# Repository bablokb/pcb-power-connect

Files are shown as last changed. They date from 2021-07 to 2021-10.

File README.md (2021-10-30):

pcb-power-connect
=================

In this repository you will find a small pcb useful if you
want to feed power to your Pi using GPIO pins 2 and 4 (e.g.
because the pi is within a housing and there is no space for
a connection to the usb-power plug of the pi).

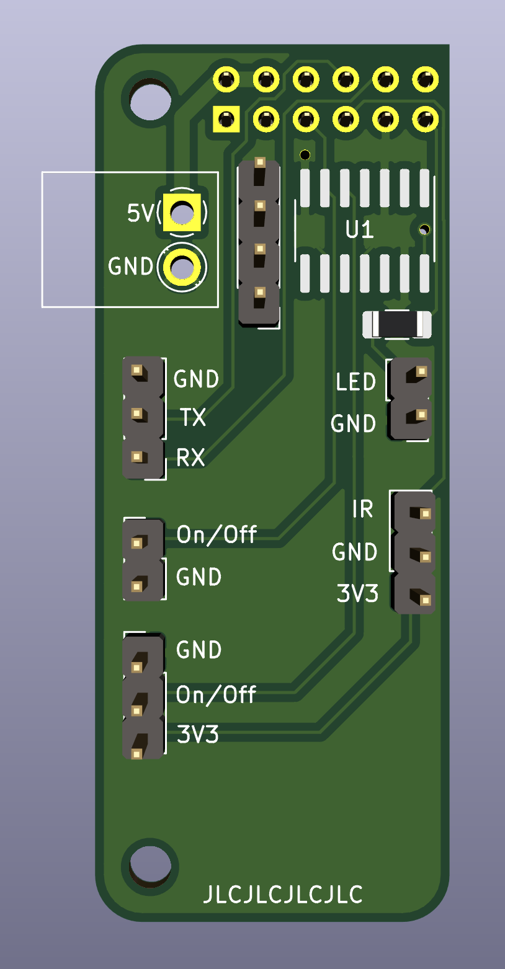
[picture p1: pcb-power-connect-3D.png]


The pcb supports some additional features

  - connect an external high->low signal (e.g. button)
    to GPIO3 (acts as on/off-switch, see below)
  - connect an external low->high signal to GPIO3 via an
    inverter (74HC05)
  - connect a LED
  - connect an IR (or something else)
  - connect an UART

 Pinout
 ------
 
  -  1: 3V3
  -  2: 5V
  -  3: GPIO2: nc
  -  4: 5V
  -  5: GPIO3: on/off
  -  6: GND
  -  7: GPIO4: IR
  -  8: GPIO14: TX
  -  9: GND
  - 10: GPIO15: RX
  - 11: GPIO17: LED
  - 12: GPIO18: nc

Configuration
-------------

Use the following configuration in `/boot/config.txt`:

    # configure GPIO3 as shutdown-button
    dtoverlay=gpio-shutdown
    
    # configure GPIO4 for IR
    dtoverlay=gpio-ir,gpio_pin=4

    # use external heartbeat-LED
    dtparam=act_led_trigger=heartbeat
    dtoverlay=act-led,gpio=17

License
-------

Shield: [![CC BY-SA 4.0][cc-by-sa-shield]][cc-by-sa]

This work is licensed under a
[Creative Commons Attribution-ShareAlike 4.0 International
License][cc-by-sa].

[][cc-by-sa]

[cc-by-sa]: http://creativecommons.org/licenses/by-sa/4.0/
[cc-by-sa-image]: https://licensebuttons.net/l/by-sa/4.0/88x31.png
[cc-by-sa-shield]:
https://img.shields.io/badge/License-CC%20BY--SA%204.0-lightgrey.svg

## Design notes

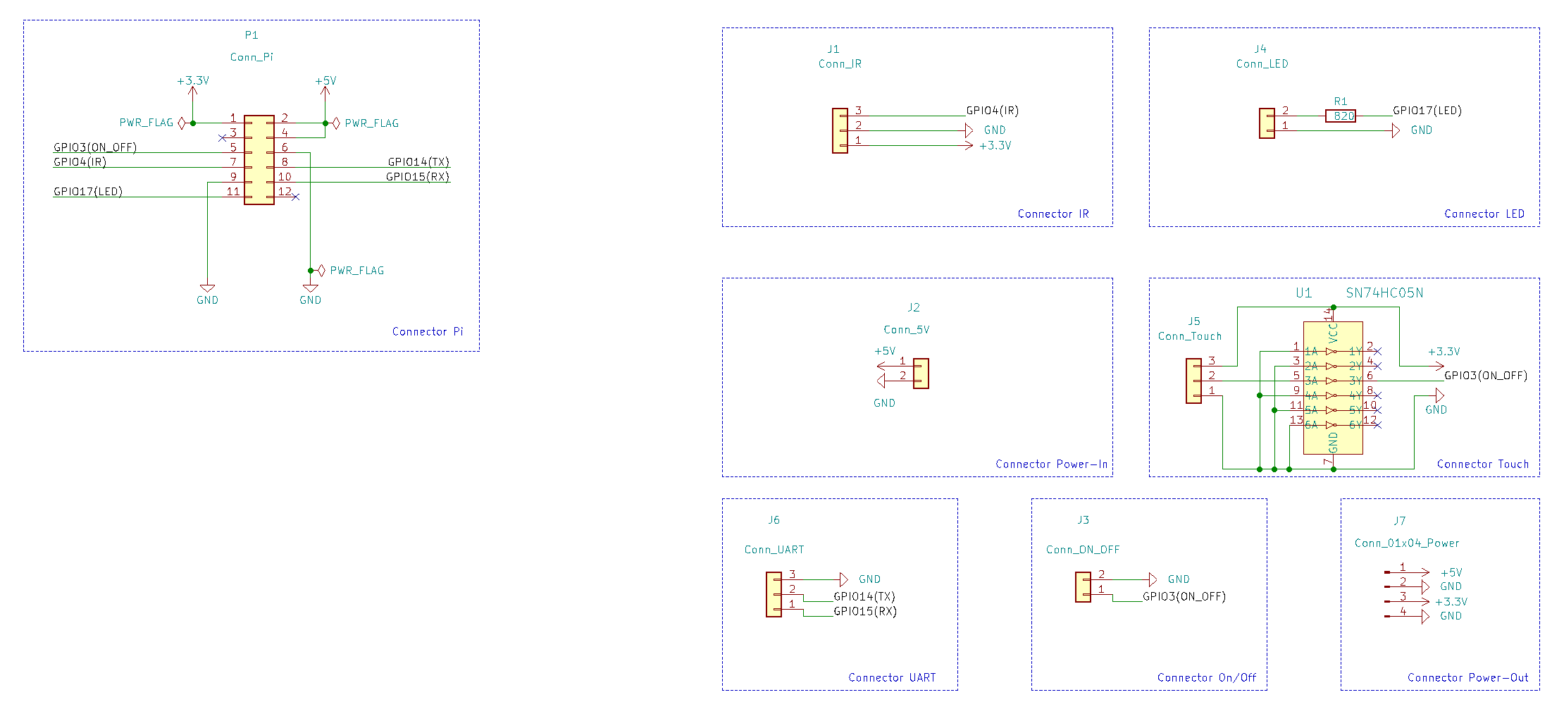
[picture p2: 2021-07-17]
pcb-power-connect-schematic.png

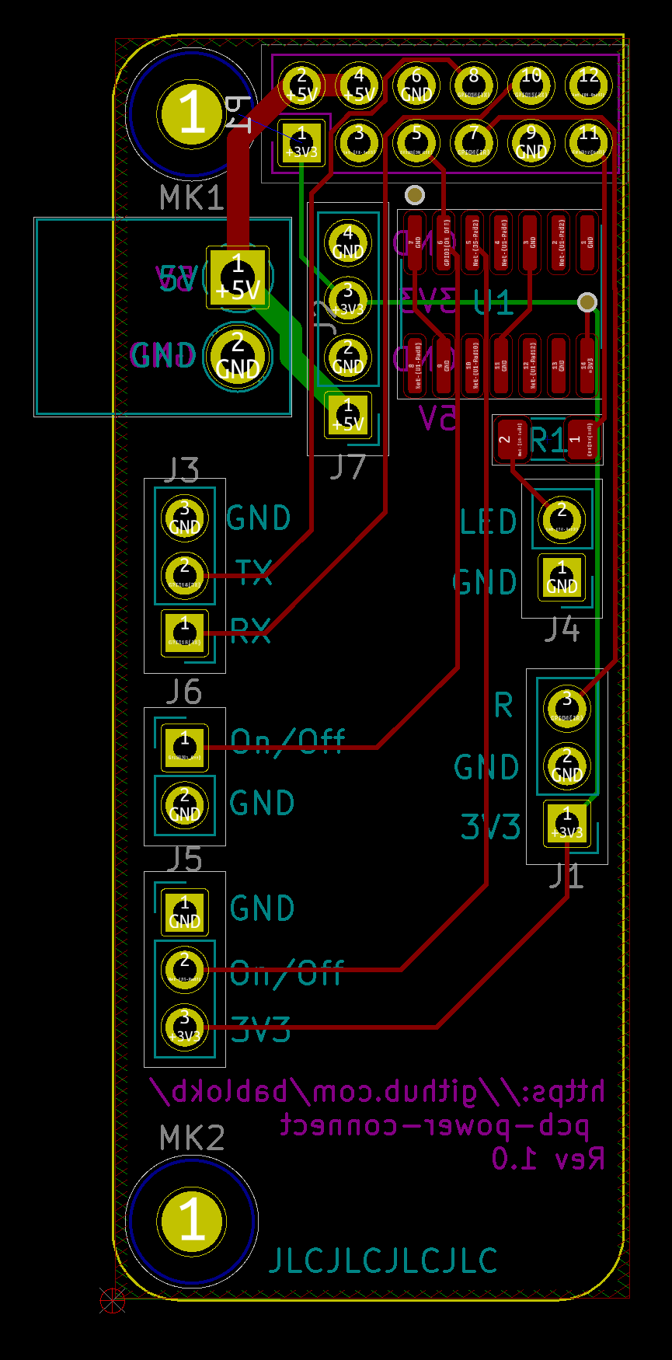
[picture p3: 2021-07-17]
pcb-power-connect-layout.png

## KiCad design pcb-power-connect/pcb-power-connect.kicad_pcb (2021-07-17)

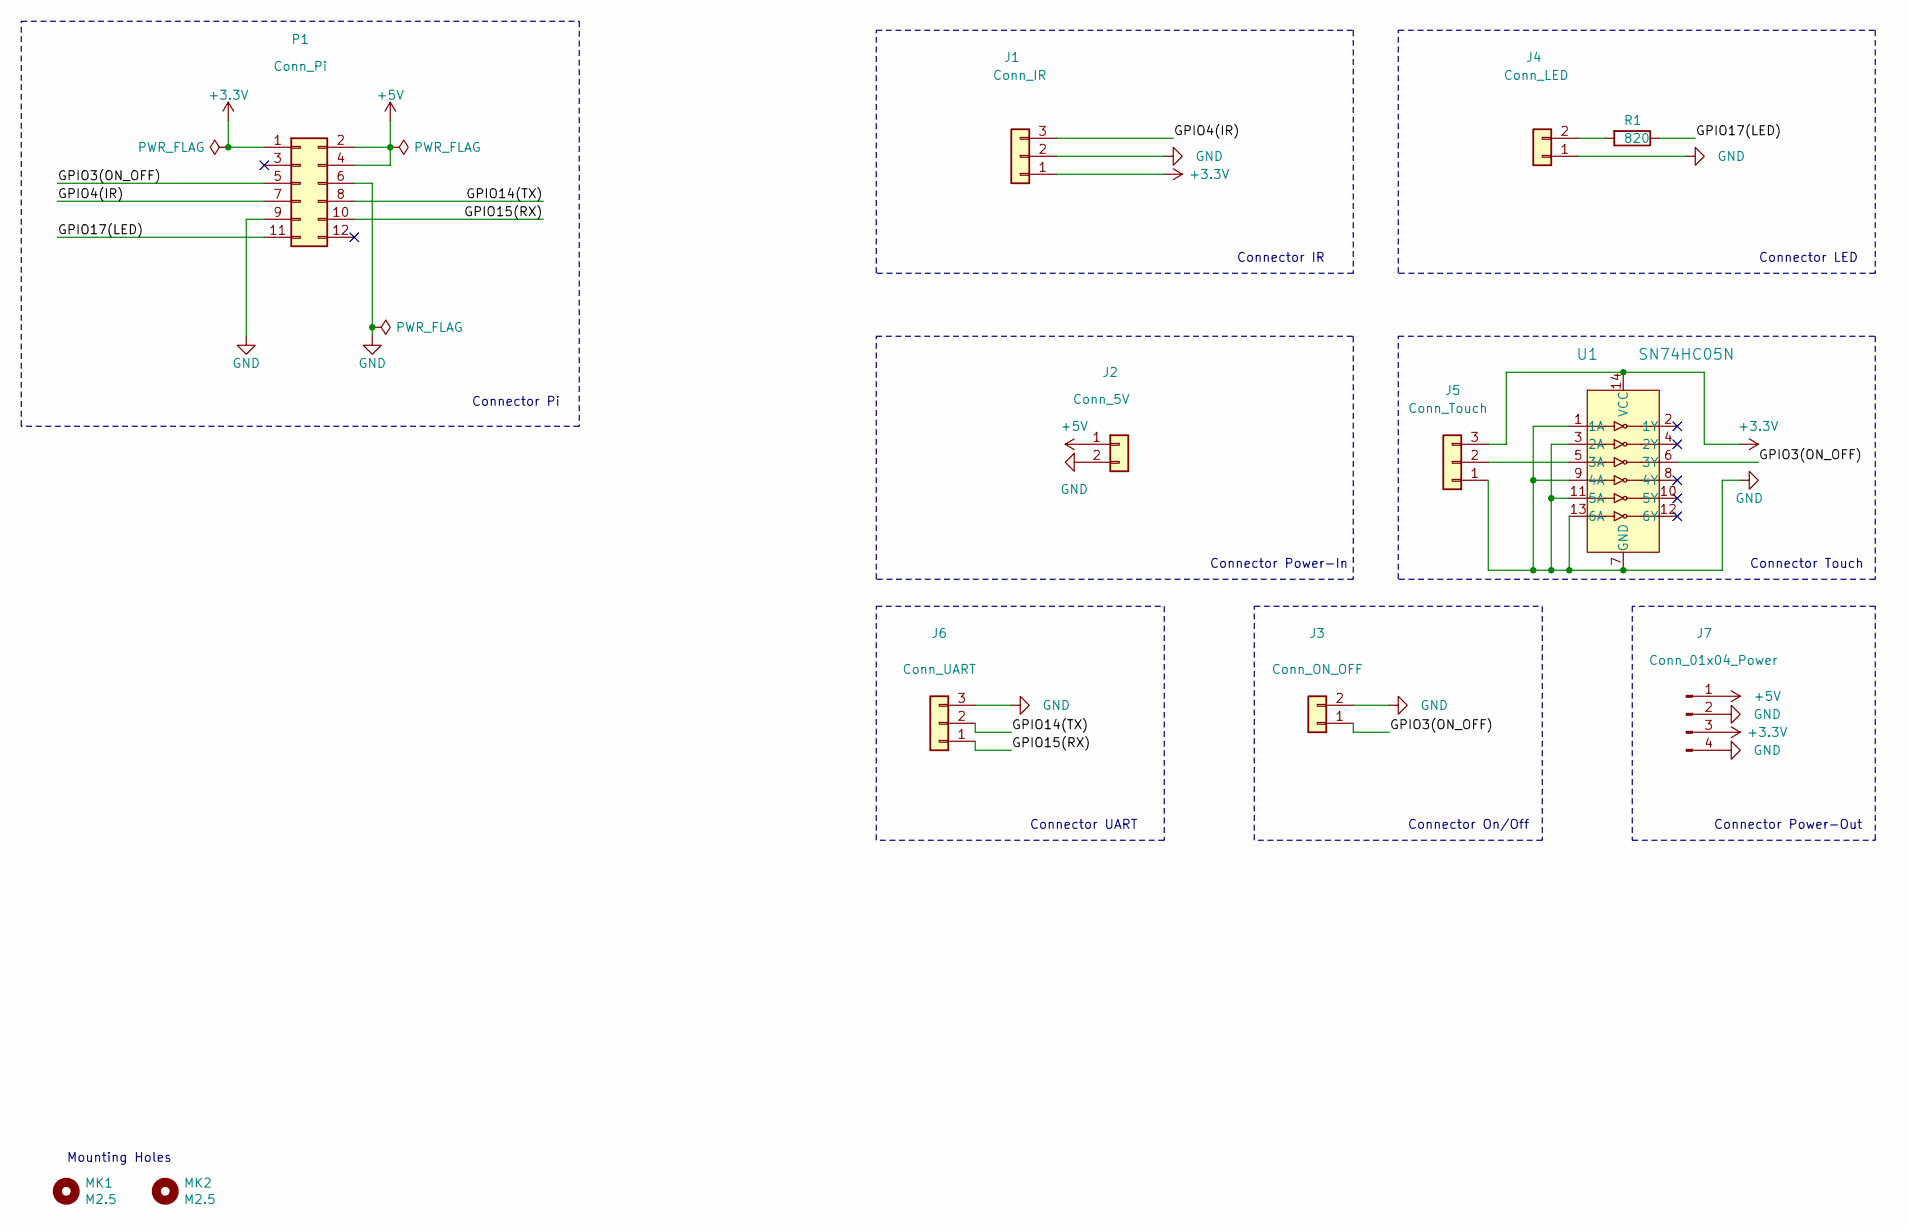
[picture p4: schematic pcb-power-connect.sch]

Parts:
J1: Conn_IR; PinHeader_1x03_P2.54mm_Vertical
J2: Conn_5V; TerminalBlock_MetzConnect_Type182_PT11302HBBN_1x02_P3.50mm_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
J3: Conn_ON_OFF; PinHeader_1x02_P2.54mm_Vertical
J4: Conn_LED; PinHeader_1x02_P2.54mm_Vertical
J5: Conn_Touch; PinHeader_1x03_P2.54mm_Vertical
J6: Conn_UART; PinHeader_1x03_P2.54mm_Vertical
J7: Conn_01x04_Power; PinHeader_1x04_P2.54mm_Vertical
MK1, MK2: M2.5; MountingHole_2.7mm_M2.5
P1: Conn_Pi; PinSocket_2x06_P2.54mm_Vertical
R1: 820; R_1206_3216Metric_Pad1.30x1.75mm_HandSolder; LCSC C17837
U1: SN74HC05N; SO-14_3.9x8.65mm_P1.27mm_HandSolder

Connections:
+3V3: J1.1, J5.3, J7.3, P1.1, U1.14 (VCC)
+5V: J2.1, J7.1, P1.2, P1.4
/GPIO3(ON_OFF): J3.1, P1.5, U1.6 (3Y)
/GPIO4(IR): J1.3, P1.7
/GPIO14(TX): J6.2, P1.8
/GPIO15(RX): J6.1, P1.10
/GPIO17(LED): P1.11, R1.1
GND: J1.2, J2.2, J3.2, J4.1, J5.1, J6.3, J7.2, J7.4, P1.6, P1.9, U1.1 (1A), U1.3 (2A), U1.7 (GND), U1.9 (4A), U1.11 (5A), U1.13 (6A)
unnamed: J4.2, R1.2
unnamed: J5.2, U1.5 (3A)

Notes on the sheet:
Mounting Holes
Connector Pi
Connector LED
Connector On/Off
Connector IR
Connector Touch
Connector Power-In
Connector UART
Connector Power-Out

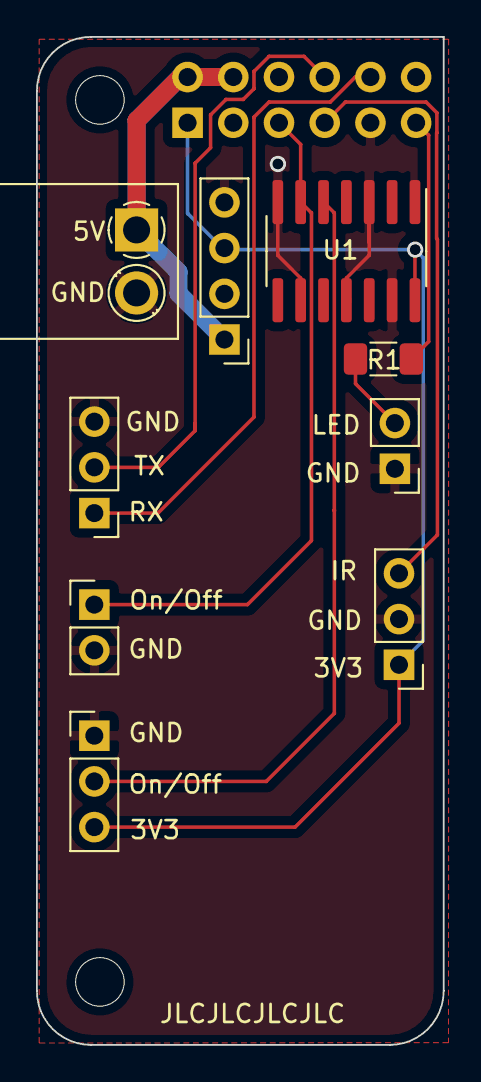
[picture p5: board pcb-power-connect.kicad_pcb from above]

Board: 2 copper layers, 22.6 x 56.0 mm, 12 parts (1 on the bottom side), 10 nets.

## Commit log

2021-07-17 link to image of pcb
2021-07-17 added LED-configuration
